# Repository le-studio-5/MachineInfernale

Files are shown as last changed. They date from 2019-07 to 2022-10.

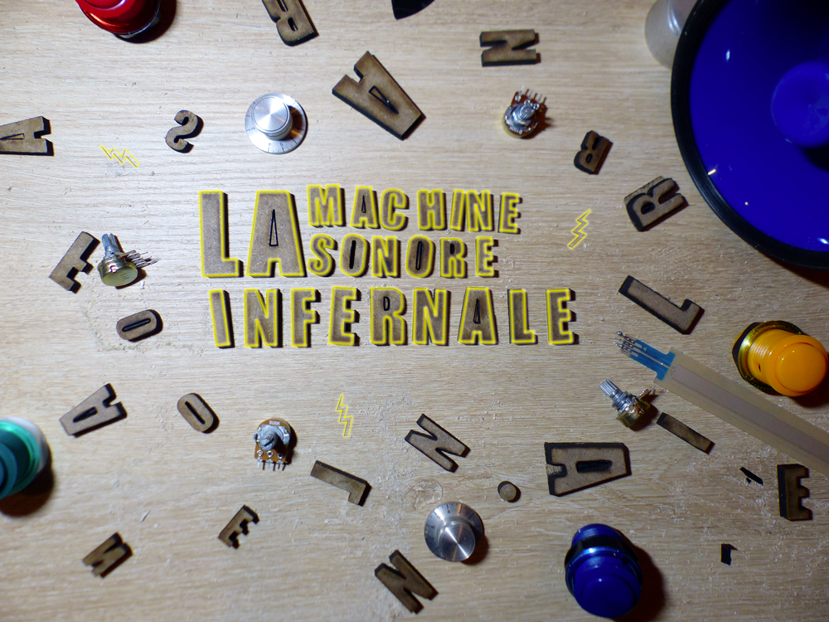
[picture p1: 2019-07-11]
visuel1.png

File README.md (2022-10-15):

# La Machine Sonore Infernale
La Machine Sonore infernale est un dispositif interactif et open source inventé par le Le Labo. Sous la forme d’un tableau de bord de vaisseau spatial, la MSI pour les intimes, permet à un groupe de 9 personnes de jouer de la musique en live.

Après avoir prototypé la Machine au Labo plusieurs partenaires sont intervenus sur le projet :
* Le studio [Kreactive](http://studiokreactive.com/) pour le design des modules
* Le [Creuset](https://creuset47asso.wixsite.com/blog) pour la partie menuiserie
* Gaël Jaton, à la réalisation électronique

Le projet a été financé par la Région Nouvelle Aquitaine ainsi que la DRAC Nouvelle Aquitaine.
Contact pierre-mary[at]le-florida.org


Ce(tte) œuvre est mise à disposition selon les termes de la [Licence Creative Commons Attribution - Partage dans les Mêmes Conditions 4.0 International.](http://creativecommons.org/licenses/by-sa/4.0/)

## Module I
### Matériel nécessaire :
* 9 boutons arcade
* 2 potentiomètres 10k Lin
* 1 joystick logitech
* 2 cartes teensy 3.6
* 1 carte sd
* alimentation mean well rs-50-5
* alimentation IRM-60-12ST
* 2x tda 2050 mono amplifier
* 2x 8ohm HP
* ruban cuivre

### Cablage
* Les boutons d'arcade sont cablés sur les entrées 0-8 de la teensy
* Les potentiomètres sur les entrées A8 et A9
* Le capteur capacitif est cablé sur l'entrée 30 après une résistance de 10kohm

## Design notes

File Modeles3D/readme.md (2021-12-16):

# Ces fichiers sont les modèles 3D utilisés pour la Machine sonore infernale.
1. Aimant = les bouchons des aimants pour le module séquenceur
2. Bouchonled = pour le ruban led du module séquenceurimprimés en PLA transparents

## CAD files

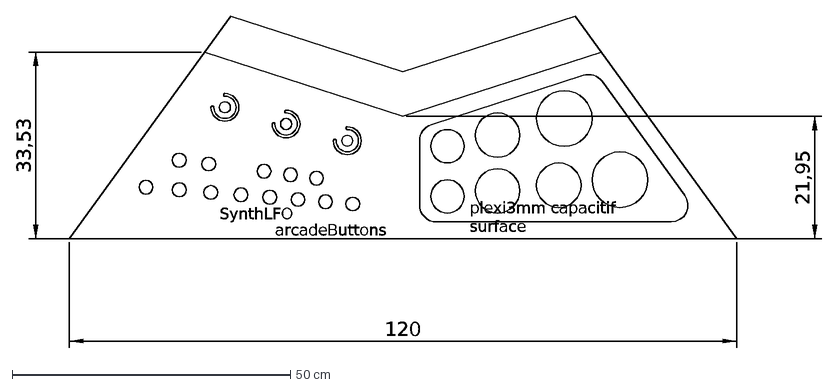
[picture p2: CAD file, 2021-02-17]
menuiserie/Dessins Modules/Module3_SynthLFOetCapacitif.dxf
120
33,53
21,95
SynthLFO
arcadeButtons
plexi3mm capacitif surface

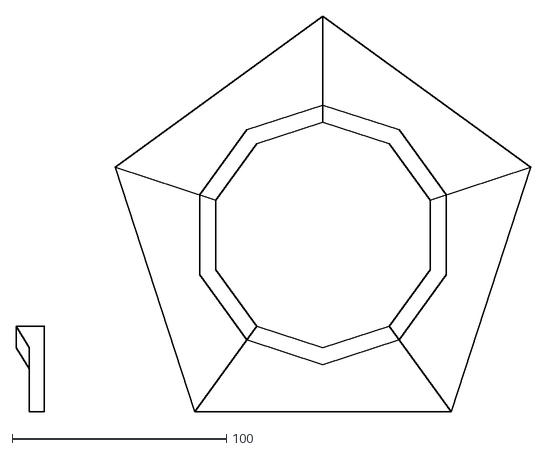
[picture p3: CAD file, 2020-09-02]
menuiserie/machine sonore infernale.dxf
240.4 x 184.7

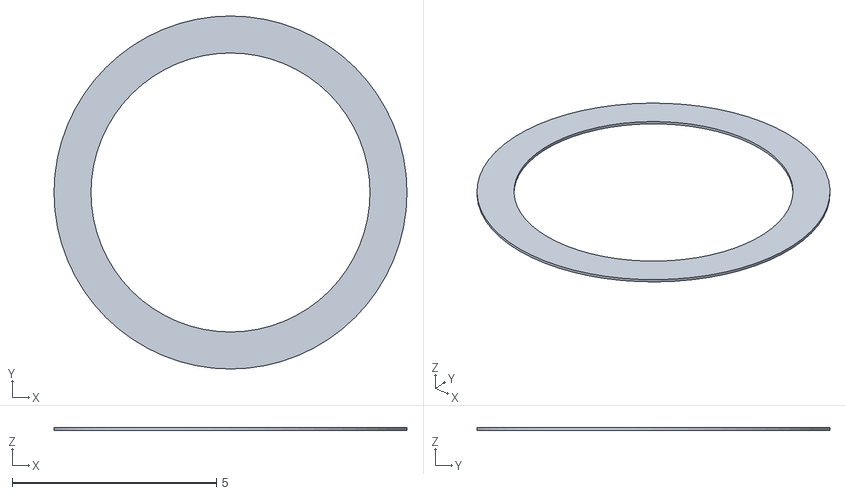
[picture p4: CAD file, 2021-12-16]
Modeles3D/cerclemsi1.stl
8.65 x 8.65 x 0.0637

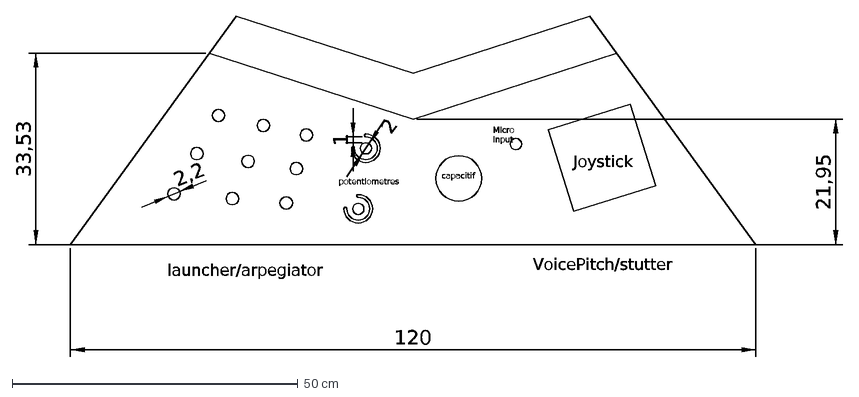
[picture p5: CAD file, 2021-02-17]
menuiserie/Dessins Modules/Module1_samplerArpEtVoiceJoystick.dxf
120
33,53
1
21,95
launcher/arpegiator
potentiometres
capacitif
Micro input
Joystick
VoicePitch/stutter
2,2
2

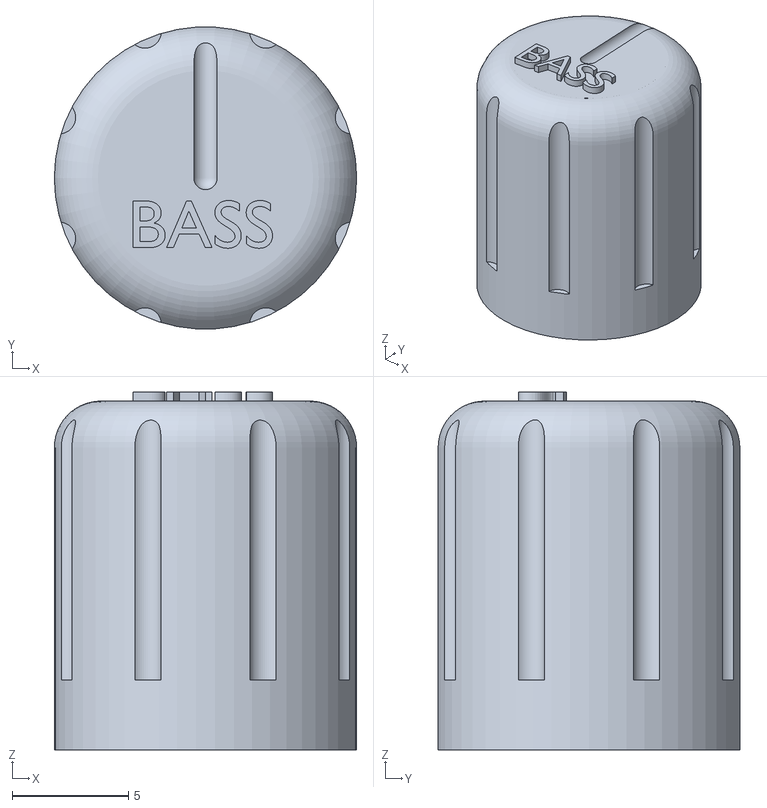
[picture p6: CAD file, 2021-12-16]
Modeles3D/bouchonbass.stl
13.0 x 13.0 x 15.4

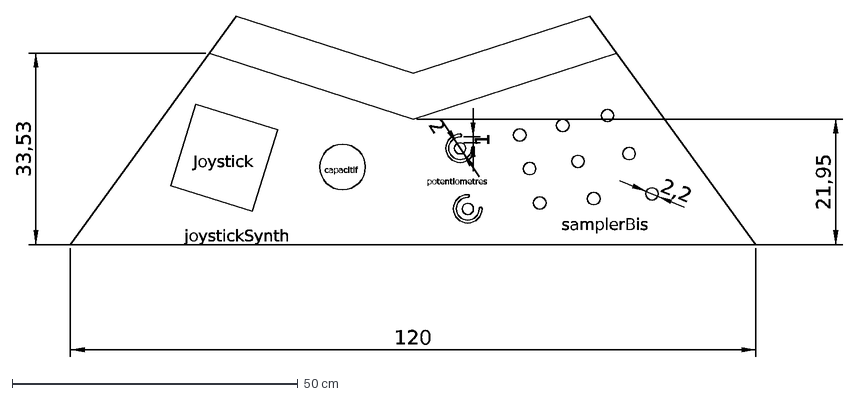
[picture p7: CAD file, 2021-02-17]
menuiserie/Dessins Modules/Module4_JoystickEtSampler.dxf
120
33,53
21,95
1
potentiometres
Joystick
2,2
2
capacitif
joystickSynth
samplerBis

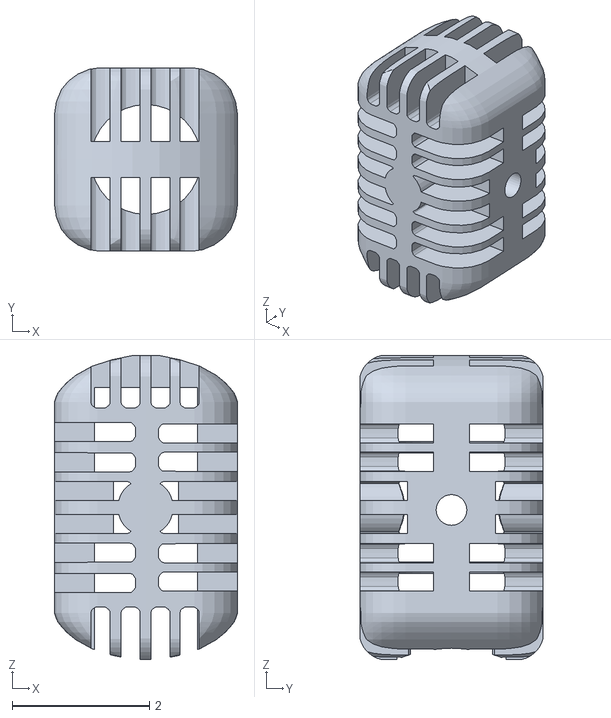
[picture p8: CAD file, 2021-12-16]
Modeles3D/micro2.stl
2.67 x 2.67 x 4.43

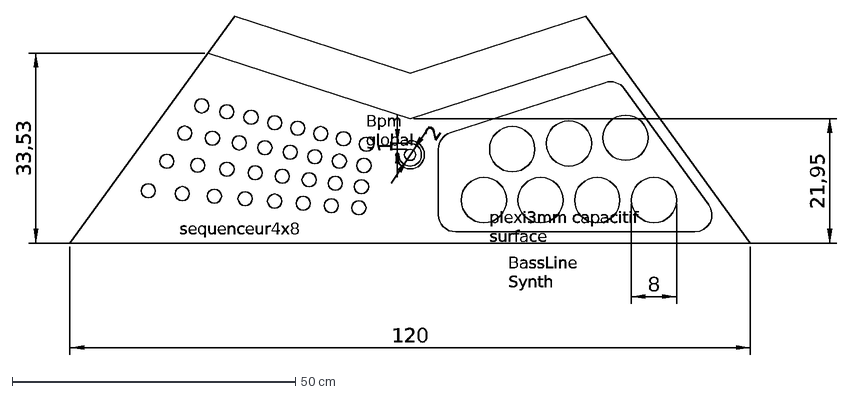
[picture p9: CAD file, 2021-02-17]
menuiserie/Dessins Modules/Module2_ssequencer4x8EtBassLine.dxf
120
33,53
21,95
sequenceur4x8
1
2
Bpm global
8
plexi3mm capacitif surface
BassLine Synth

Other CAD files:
Modeles3D/AIMANT.blend
Modeles3D/bouchon led.blend

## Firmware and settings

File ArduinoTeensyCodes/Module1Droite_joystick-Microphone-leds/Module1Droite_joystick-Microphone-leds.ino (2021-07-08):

// Joystick Logitec extreme3Dpro to teensy3.6 avec Mic PDM
#include <Audio.h>
#include <Wire.h>
#include <SPI.h>
#include <SD.h>
#include <SerialFlash.h>
AudioInputPDM            pdm1;           //xy=218.88888888888889,241.11111111111111
AudioEffectGranular      granular1;      //xy=372.22216796875,159.9999542236328
AudioEffectBitcrusher    bitcrusher1;    //xy=543.3333129882812,161.11109924316406
AudioOutputAnalogStereo  dacs1;          //xy=685.888916015625,246.88890075683594
AudioConnection          patchCord1(pdm1, granular1);
AudioConnection          patchCord2(granular1, bitcrusher1);
AudioConnection          patchCord3(bitcrusher1, 0, dacs1, 0);
AudioConnection          patchCord4(bitcrusher1, 0, dacs1, 1);
// GUItool: end automatically generated code
#define GRANULAR_MEMORY_SIZE 12800  // 12800 enough for 290 ms at 44.1 kHz
int16_t granularMemory[GRANULAR_MEMORY_SIZE];
#include "USBHost_t36.h"
USBHost             usbHost1;
USBHIDParser        usbHid1( usbHost1 );
JoystickController  stick( usbHost1 );
#include <FastLED.h>
CRGB leds[3];
bool freeze = 0;
bool bouton[13];
bool buttonFlag[3] = {0};

void setup( ) {
  Serial.begin(9600);
  AudioMemory(30);
  usbHost1.begin();
  bitcrusher1.bits(16); /////////////////
  bitcrusher1.sampleRate(44100);
  granular1.begin(granularMemory, GRANULAR_MEMORY_SIZE);
  //granular1.beginPitchShift(25);
  FastLED.addLeds<WS2812B, 0, GRB>(leds, 3);
//  for (int i = 0; 1 < 3; i++) {
//    leds[i].r = 255;
//    leds[i].g = 0;
//  }
//  FastLED.show();
}

void loop() {
  usbHost1.Task();
  int Xjoy = stick.getAxis( 0 );
  int Yjoy = stick.getAxis( 1 );
  int Zjoy = stick.getAxis( 5 );
  int Cross = stick.getAxis( 9 );
  uint32_t buttons = stick.getButtons();
  Serial.println("top");
  for (int i = 1; i < 13; i++) { ///////////////////à tester...
    bouton[i] = (buttons >> (i - 1)) & 1;
    Serial.println( bouton[i]);
  }
  if (bouton[2]) bitcrusher1.bits(1);
  else if (bouton[3]) bitcrusher1.bits(2);
  else if (bouton[4]) bitcrusher1.bits(3);
  else if (bouton[5]) bitcrusher1.bits(4);
  else if (bouton[6]) bitcrusher1.bits(4);
  else bitcrusher1.bits(16);
  ///////// fin à tester
  long SR =  sq(1023 - Yjoy) / 40;
  //Serial.print( buttons, BIN);

  bitcrusher1.sampleRate(SR);
  if (bouton[1] == 1 && freeze == 0) {
    freeze = 1;
    float msec = 10 + (1023 - Xjoy) / 2; //500.0; // + (knobA3 * 190.0);
    granular1.beginFreeze(msec);
  }
  if (bouton[1] == 0 && freeze == 1) {
    freeze = 0;
    granular1.stop();
  }
  if (bouton[7] == 1 &&  buttonFlag[0] == 0) { //Boutton 7 effet 1 ON
    buttonFlag[0] = 1;
    leds[0].r = 0;
    leds[0].g = 200;
    FastLED.show();

  }
  if (bouton[8] == 1 &&  buttonFlag[0] == 1) { //Boutton 8 effet 1 OFF
    buttonFlag[0] = 0;
    leds[0].r = 255;
    leds[0].g = 0;
    FastLED.show();
  }
  if (bouton[9] == 1 &&  buttonFlag[1] == 0) { //Boutton 9 effet 2 ON
    buttonFlag[1] = 1;
    leds[1].r = 0;
    leds[1].g = 200;
    FastLED.show();

  }
  if (bouton[10] == 1 &&  buttonFlag[1] == 1) { //Boutton 10 effet 2 OFF
    buttonFlag[1] = 0;
    leds[1].r = 255;
    leds[1].g = 0;
    FastLED.show();
  }
  if (bouton[11] == 1 &&  buttonFlag[2] == 0) { //Boutton 11 effet 3 ON
    buttonFlag[2] = 1;
    leds[2].r = 0;
    leds[2].g = 200;
    FastLED.show();
    granular1.beginPitchShift(10);
  }
  if (bouton[12] == 1 &&  buttonFlag[2] == 1) { //Boutton 12 effet 3 OFF
    buttonFlag[2] = 0;
    leds[2].r = 255;
    leds[2].g = 0;
    FastLED.show();
    granular1.stop();
  }
  //
  if (freeze == 1) {
    float ratio;
    if (Zjoy >= 0 && Zjoy < 32) ratio = 0.25;
    if (Zjoy >= 32 && Zjoy < 96) ratio = 0.5;
    if (Zjoy >= 96 && Zjoy < 160) ratio = 1.0;
    if (Zjoy >= 160 && Zjoy < 224) ratio = 2.0;
    if (Zjoy >= 224 && Zjoy < 256) ratio = 4.0;
    //ratio = powf(2.0, (Zjoy)/255.0 * 2.0 - 1.0); // 0.5 to 2.0
    //ratio = powf(2.0, knobA2 * 6.0 - 3.0); // 0.125 to 8.0 -- uncomment for far too much range!
    granular1.setSpeed(ratio);
  }
  else {
    float pitch = Xjoy / 1024.0;
    pitch = map(pitch, 0.0, 1.0, 0.75, 1.25);
    granular1.setSpeed(pitch);
  }
  delay(10);
}

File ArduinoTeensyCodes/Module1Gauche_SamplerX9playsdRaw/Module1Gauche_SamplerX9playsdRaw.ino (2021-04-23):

#define bounceTime 20
#include <Bounce.h>
Bounce bouncer0 = Bounce( 0, bounceTime );
Bounce bouncer1 = Bounce( 1, bounceTime );
Bounce bouncer2 = Bounce( 2, bounceTime );
Bounce bouncer3 = Bounce( 3, bounceTime );
Bounce bouncer4 = Bounce( 4, bounceTime );
Bounce bouncer5 = Bounce( 5, bounceTime );
Bounce bouncer6 = Bounce( 6, bounceTime );
Bounce bouncer7 = Bounce( 7, bounceTime );
Bounce bouncer8 = Bounce( 8, bounceTime );
#include <Audio.h>
#include <Wire.h>
#include <SPI.h>
#include <SD.h>
#include <SerialFlash.h>
#define LED 13
// GUItool: begin automatically generated code
AudioPlaySdRaw           playSdRaw0;     //xy=107,22
AudioPlaySdRaw           playSdRaw1;     //xy=144,53
AudioPlaySdRaw           playSdRaw2;     //xy=173,83
AudioPlaySdRaw           playSdRaw3;     //xy=199,114
AudioPlaySdRaw           playSdRaw4;     //xy=224,146
AudioPlaySdRaw           playSdRaw5;     //xy=252,182
AudioPlaySdRaw           playSdRaw6;     //xy=275,215
AudioPlaySdRaw           playSdRaw7;     //xy=300,248
AudioPlaySdRaw           playSdRaw8;     //xy=333,280
AudioMixer4              mixer1;         //xy=440,67
AudioMixer4              mixer2;         //xy=488,158
AudioMixer4              mixer3;         //xy=647,215
AudioOutputAnalogStereo  dacs;          //xy=825,247
AudioConnection          patchCord1(playSdRaw0, 0, mixer1, 0);
AudioConnection          patchCord2(playSdRaw1, 0, mixer1, 1);
AudioConnection          patchCord3(playSdRaw2, 0, mixer1, 2);
AudioConnection          patchCord4(playSdRaw3, 0, mixer1, 3);
AudioConnection          patchCord5(playSdRaw4, 0, mixer2, 0);
AudioConnection          patchCord6(playSdRaw5, 0, mixer2, 1);
AudioConnection          patchCord7(playSdRaw6, 0, mixer2, 2);
AudioConnection          patchCord8(playSdRaw7, 0, mixer2, 3);
AudioConnection          patchCord9(playSdRaw8, 0, mixer3, 2);
AudioConnection          patchCord10(mixer1, 0, mixer3, 0);
AudioConnection          patchCord11(mixer2, 0, mixer3, 1);
AudioConnection          patchCord12(mixer3, 0, dacs, 0);
AudioConnection          patchCord13(mixer3, 0, dacs, 1);
// Use these with the Teensy 3.5 & 3.6 SD card
#define SDCARD_CS_PIN    BUILTIN_SDCARD
#define SDCARD_MOSI_PIN  11  // not actually used
#define SDCARD_SCK_PIN   13  // not actually used
uint8_t pinBouton[9] = {0, 1, 2, 3, 4, 5, 6, 7, 8};

void setup() {
  AudioMemory(30);
  pinMode(13, OUTPUT);
  for (int i = 0; i < 9; i++) {
    pinMode(pinBouton[i], INPUT_PULLUP);
  }
  SPI.setMOSI(SDCARD_MOSI_PIN);
  SPI.setSCK(SDCARD_SCK_PIN);
  while (!(SD.begin(SDCARD_CS_PIN))) {
    digitalWrite(13, LOW);
    delay (100);
    digitalWrite(13, HIGH);
    delay (100);
  }
  digitalWrite(13, HIGH);
  delay(100);
  mixer3.gain(0, 0.7);
  mixer3.gain(1, 0.7);
  mixer3.gain(2, 0.7);
  mixer3.gain(3, 0.7);
}
void loop() {
  // ++ deux potentiomètres => bitcrusher / stutter / 
  bouncer0.update ( );
  bouncer1.update ( );
  bouncer2.update ( );
  bouncer3.update ( );
  bouncer4.update ( );
  bouncer5.update ( );
  bouncer6.update ( );
  bouncer7.update ( );
  bouncer8.update ( );
  if ( bouncer0.fallingEdge()) {
    playSdRaw0.play("s0.raw");
  }
  if ( bouncer1.fallingEdge()) {
    playSdRaw1.play("s1.raw");
  }
  if ( bouncer2.fallingEdge()) {
    playSdRaw2.play("s2.raw");
  }
  if ( bouncer3.fallingEdge()) {
    playSdRaw3.play("s3.raw");
  }
  if ( bouncer4.fallingEdge()) {
    playSdRaw4.play("s4.raw");
  }
  if ( bouncer5.fallingEdge()) {
    playSdRaw5.play("s5.raw");
  }
  if ( bouncer6.fallingEdge()) {
    playSdRaw6.play("s6.raw");
  }
  if ( bouncer7.fallingEdge()) {
    playSdRaw7.play("s7.raw");
  }
  if ( bouncer8.fallingEdge()) {
    playSdRaw8.play("s8.raw");
  }
}

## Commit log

2019-07-11 Create visuel1.png
    Premier visuel pour la communication
2020-02-14 test pour usb host intégré au Teensy3.6 et joystick USB
2020-02-29 le sampler 4 piste ok
2021-02-17 dessins modules provisoires
    [Module1_samplerArpEtVoiceJoystick.dxf, Module2_ssequencer4x8EtBassLine.dxf, Module3_SynthLFOetCapacitif.dxf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]
2021-07-30 Last codes
    salut PM, les derniers codes en vrac, tu peux les renomer avec le bon numéro de module... j'ai plus en tête :)
2021-12-16 D'autres modèles 3D
    [bouchonbass.stl, cerclemsi1.stl, micro2.stl]
